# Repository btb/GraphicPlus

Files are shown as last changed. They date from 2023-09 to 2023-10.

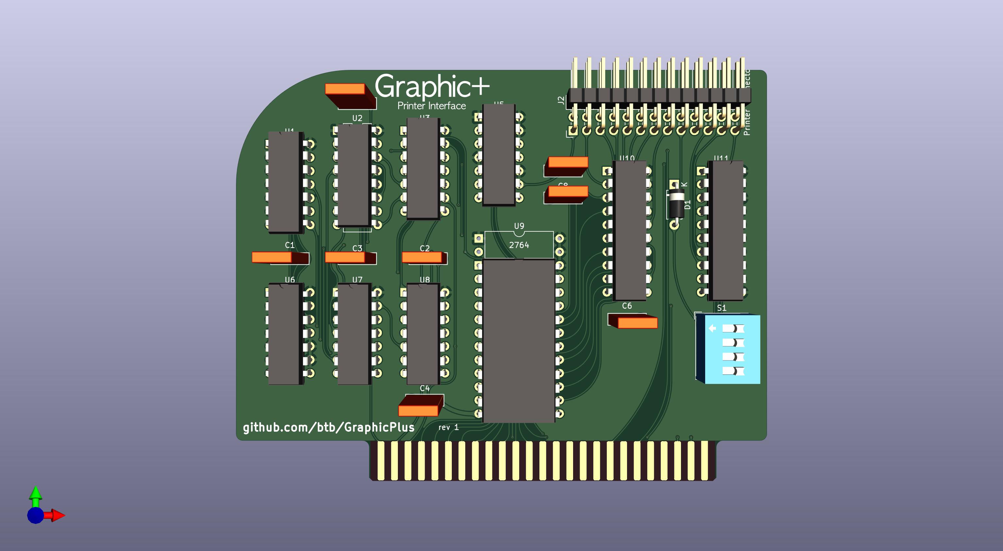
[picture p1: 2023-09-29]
GraphicPlus.jpg

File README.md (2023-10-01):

# GraphicPlus

Parallel printer card for Apple II

A clone of Orange Micro's Grappler+ printer card, from their published schematic, with the known bugfixes of their later revisions applied.

Component values not specified on the original schematic:

* C2, C4, C5, C5 - bypass capactors, 100nF should be fine.
* C1, C3, C7, C8 - on photos I've seen, C1 is 100pF, C3 is 470pF, C7 is 100pF. 100p for C8 should be fine as well.
* D1 - signal diode, 1n4148, 1n914, etc should be fine.

If you only want to use this as a firmware expansion card (i.e. for SoftSP), you can omit U5, U6, U10, U11, S1, D1, and J2.

Pins 2,4,6,8 of the port header are left unconnected for maximum compatibility with common PC parallel port IDC26F to DB25F dongles. If you need those pins to be connected to ground as in the original Grappler cards, short jumpers JP1,JP2,JP3,JP4.

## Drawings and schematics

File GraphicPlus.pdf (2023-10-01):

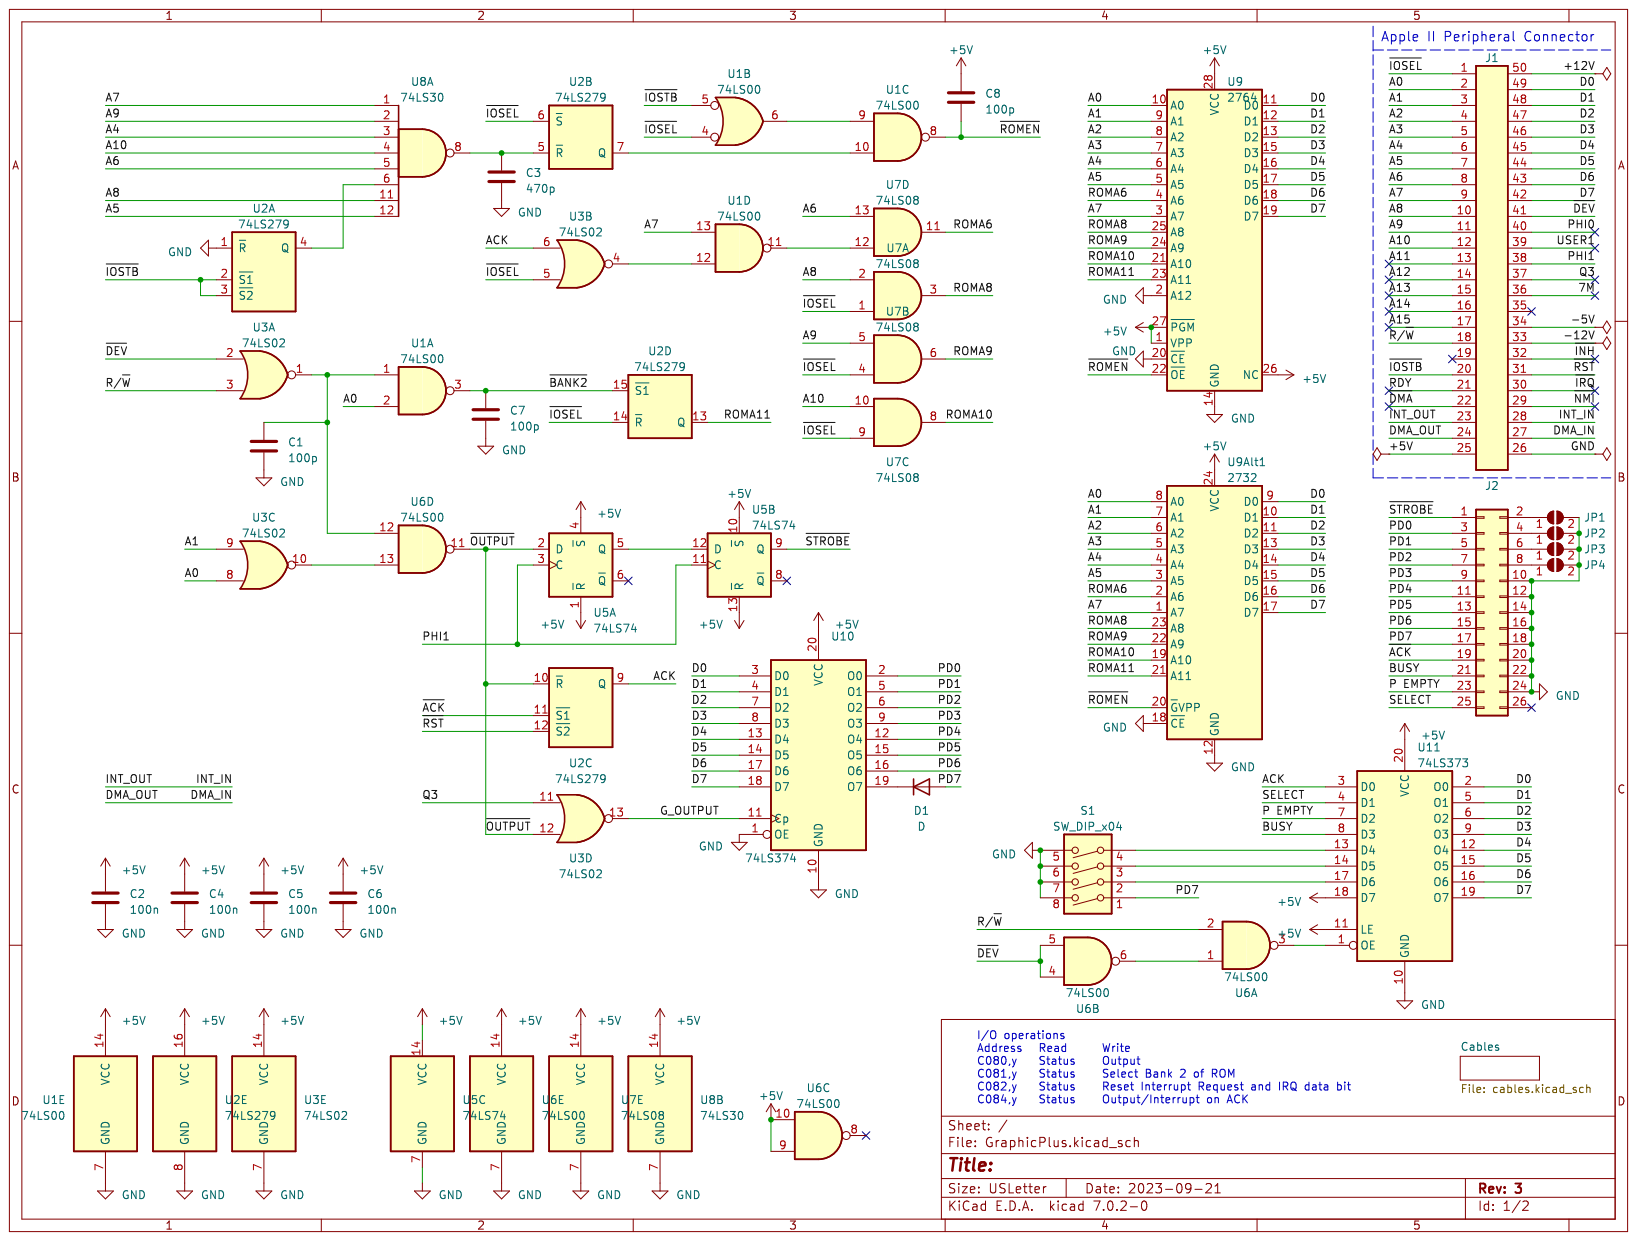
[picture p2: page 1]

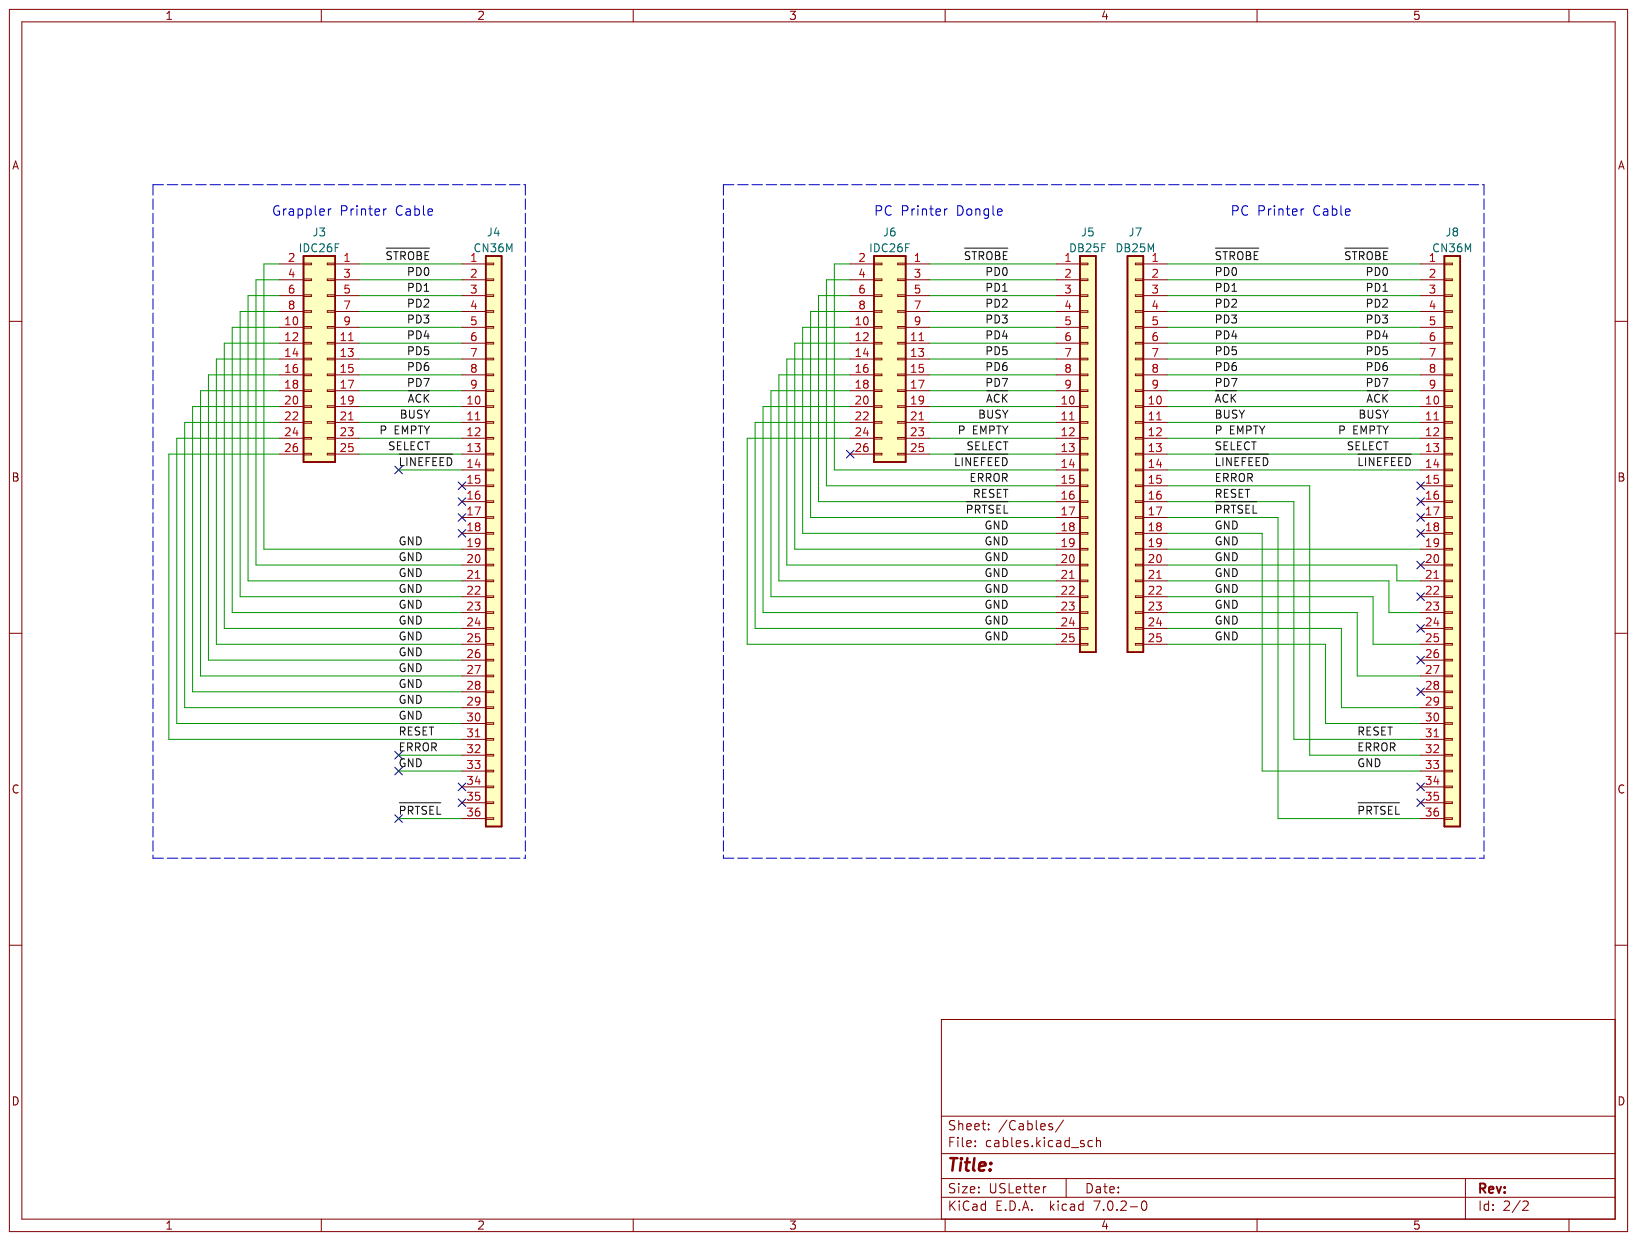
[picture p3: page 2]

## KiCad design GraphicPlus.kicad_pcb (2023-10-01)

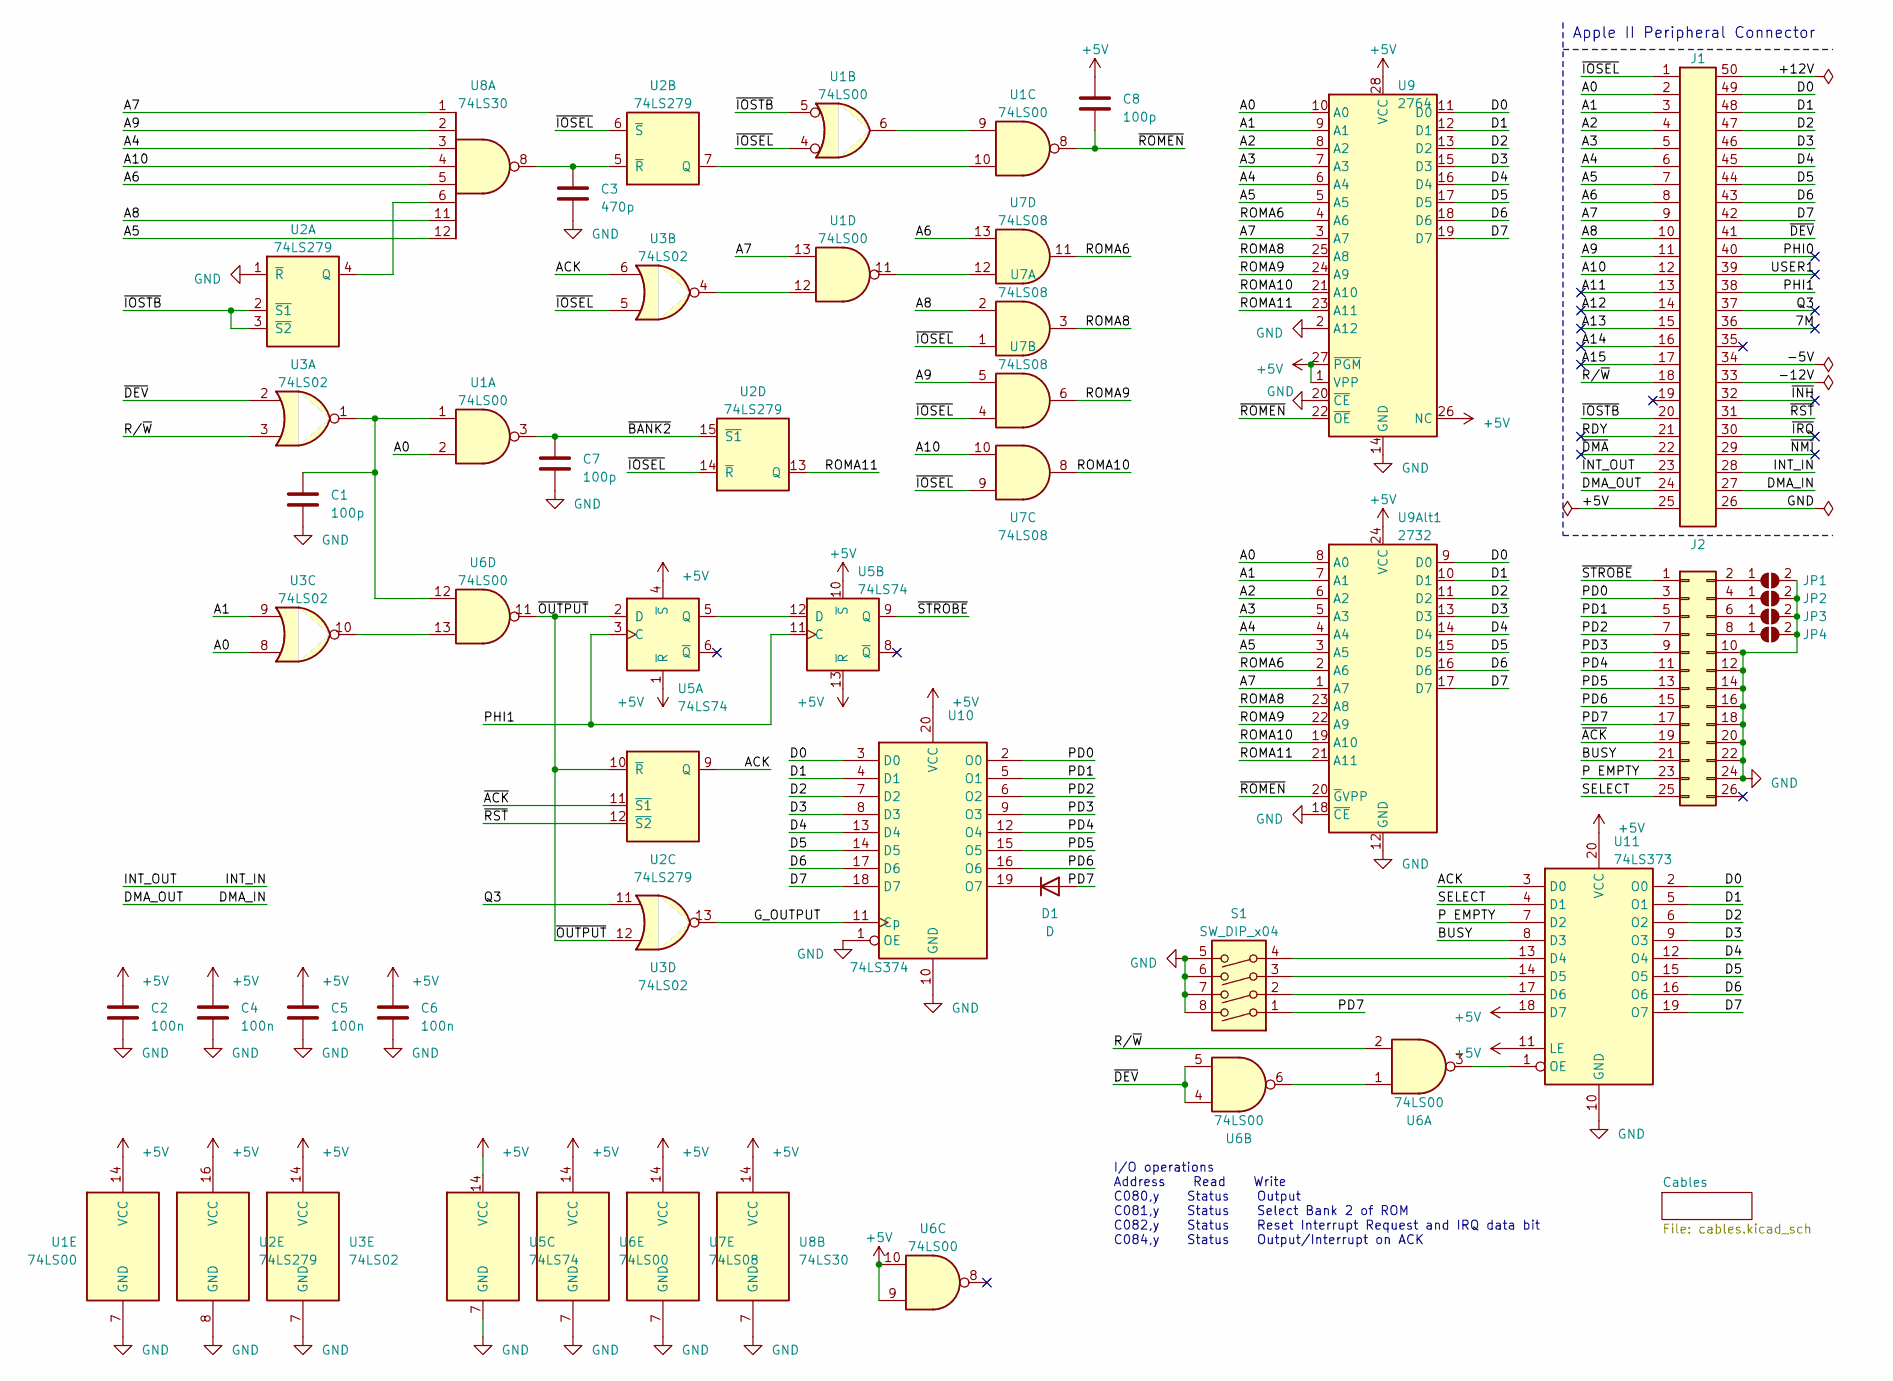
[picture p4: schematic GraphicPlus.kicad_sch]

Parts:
C1, C7, C8: 100p; C_Rect_L7.0mm_W2.0mm_P5.00mm
C2, C4, C5, C6: 100n; C_Rect_L7.0mm_W2.0mm_P5.00mm
C3: 470p; C_Rect_L7.0mm_W2.0mm_P5.00mm
D1: D; D_A-405_P7.62mm_Horizontal
J1: Apple II Expansion Bus; Apple II Expansion Edge Connector
J2: Printer Connector; PinHeader_2x13_P2.54mm_Horizontal
JP1, JP2, JP3, JP4: SolderJumper-2_P1.3mm_Open_RoundedPad1.0x1.5mm
S1: SW_DIP_x04; SW_DIP_SPSTx04_Slide_9.78x12.34mm_W7.62mm_P2.54mm
U1, U6: 74LS00; DIP-14_W7.62mm
U2: 74LS279; DIP-16_W7.62mm
U3: 74LS02; DIP-14_W7.62mm
U5: 74LS74; DIP-14_W7.62mm
U7: 74LS08; DIP-14_W7.62mm
U8: 74LS30; DIP-14_W7.62mm
U9: 2764; DIP-28_W15.24mm
U9Alt1: 2732; DIP-24_W15.24mm
U10: 74LS374; DIP-20_W7.62mm
U11: 74LS373; DIP-20_W7.62mm

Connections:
+5V: C2.1, C4.1, C5.1, C6.1, C8.1, J1.25 (+5V), U1.14 (VCC), U2.16 (VCC), U3.14 (VCC), U5.1 (~R), U5.4 (~S), U5.10 (~S), U5.13 (~R), U5.14 (VCC), U6.9, U6.10, U6.14 (VCC), U7.14 (VCC), U8.14 (VCC), U9.1 (VPP), U9.26 (NC), U9.27 (~PGM), U9.28 (VCC), U9Alt1.24 (VCC), U10.20 (VCC), U11.11 (LE), U11.18 (D7), U11.20 (VCC)
/7M: J1.36 (7M)
/+12V: J1.50 (-12V)
/-5V: J1.34 (-5V)
/-12V: J1.33 (-12V)
/A0: J1.2 (A00), U1.2, U3.8, U9.10 (A0), U9Alt1.8 (A0)
/A1: J1.3 (A01), U3.9, U9.9 (A1), U9Alt1.7 (A1)
/A2: J1.4 (A02), U9.8 (A2), U9Alt1.6 (A2)
/A3: J1.5 (A03), U9.7 (A3), U9Alt1.5 (A3)
/A4: J1.6 (A04), U8.3, U9.6 (A4), U9Alt1.4 (A4)
/A5: J1.7 (A05), U8.12, U9.5 (A5), U9Alt1.3 (A5)
/A6: J1.8 (A06), U7.13, U8.5
/A7: J1.9 (A07), U1.13, U8.1, U9.3 (A7), U9Alt1.1 (A7)
/A8: J1.10 (A08), U7.2, U8.11
/A9: J1.11 (A09), U7.5, U8.2
/A10: J1.12 (A10), U7.10, U8.4
/A11: J1.13 (A11)
/A12: J1.14 (A12)
/A13: J1.15 (A13)
/A14: J1.16 (A14)
/A15: J1.17 (A15)
/ACK: U2.9 (Q), U3.6, U11.3 (D0)
/BUSY: J2.21, U11.8 (D3)
/D0: J1.49 (D0), U9.11 (D0), U9Alt1.9 (D0), U10.3 (D0), U11.2 (O0)
/D1: J1.48 (D1), U9.12 (D1), U9Alt1.10 (D1), U10.4 (D1), U11.5 (O1)
/D2: J1.47 (D2), U9.13 (D2), U9Alt1.11 (D2), U10.7 (D2), U11.6 (O2)
/D3: J1.46 (D3), U9.15 (D3), U9Alt1.13 (D3), U10.8 (D3), U11.9 (O3)
/D4: J1.45 (D4), U9.16 (D4), U9Alt1.14 (D4), U10.13 (D4), U11.12 (O4)
/D5: J1.44 (D5), U9.17 (D5), U9Alt1.15 (D5), U10.14 (D5), U11.15 (O5)
/D6: J1.43 (D6), U9.18 (D6), U9Alt1.16 (D6), U10.17 (D6), U11.16 (O6)
/D7: J1.42 (D7), U9.19 (D7), U9Alt1.17 (D7), U10.18 (D7), U11.19 (O7)
/DMA_IN: J1.24 (DMA_OUT), J1.27 (DMA_IN)
/G_OUTPUT: U3.13, U10.11 (Cp)
/INT_IN: J1.23 (INT_OUT), J1.28 (INT_IN)
/P EMPTY: J2.23, U11.7 (D2)
/PD0: J2.3, U10.2 (O0)
/PD1: J2.5, U10.5 (O1)
/PD2: J2.7, U10.6 (O2)
/PD3: J2.9, U10.9 (O3)
/PD4: J2.11, U10.12 (O4)
/PD5: J2.13, U10.15 (O5)
/PD6: J2.15, U10.16 (O6)
/PD7: D1.2 (A), J2.17, S1.1
/PHI0: J1.40 (PHI0)
/PHI1: J1.38 (PHI1), U5.3 (C), U5.11 (C)
/Q3: J1.37 (Q3), U3.11
/RDY: J1.21 (RDY)
/ROMA6: U7.11, U9.4 (A6), U9Alt1.2 (A6)
/ROMA8: U7.3, U9.25 (A8), U9Alt1.23 (A8)
/ROMA9: U7.6, U9.24 (A9), U9Alt1.22 (A9)
/ROMA10: U7.8, U9.21 (A10), U9Alt1.19 (A10)
/ROMA11: U2.13 (Q), U9.23 (A11), U9Alt1.21 (A11)
/R/~W: J1.18 (R/~W), U3.3, U6.2
/SELECT: J2.25, U11.4 (D1)
/USER1: J1.39 (USER1)
/~ACK: J2.19, U2.11 (~S1)
/~BANK2: C7.1, U1.3, U2.15 (~S1)
/~DEV: J1.41 (~DEVICE_SELECT), U3.2, U6.4, U6.5
/~DMA: J1.22 (~DMA)
/~INH: J1.32 (~INH)
/~IOSEL: J1.1 (~IO_SELECT), U1.4, U2.6 (~S), U2.14 (~R), U3.5, U7.1, U7.4, U7.9
/~IOSTB: J1.20 (~I/O_STROBE), U1.5, U2.2 (~S1), U2.3 (~S2)
/~IRQ: J1.30 (~IRQ)
/~NMI: J1.29 (~NMI)
/~OUTPUT: U2.10 (~R), U3.12, U5.2 (D), U6.11
/~ROMEN: C8.2, U1.8, U9.22 (~OE), U9Alt1.20 (~GVPP)
/~RST: J1.31 (~RES), U2.12 (~S2)
/~STROBE: J2.1, U5.9 (Q)
GND: C1.2, C2.2, C3.2, C4.2, C5.2, C6.2, C7.2, J1.26 (GND), J2.10, J2.12, J2.14, J2.16, J2.18, J2.20, J2.22, J2.24, JP1.2 (B), JP2.2 (B), JP3.2 (B), JP4.2 (B), S1.5, S1.6, S1.7, S1.8, U1.7 (GND), U2.1 (~R), U2.8 (GND), U3.7 (GND), U5.7 (GND), U6.7 (GND), U7.7 (GND), U8.7 (GND), U9.2 (A12), U9.14 (GND), U9.20 (~CE), U9Alt1.12 (GND), U9Alt1.18 (~CE), U10.1 (OE), U10.10 (GND), U11.10 (GND)
unnamed: C1.1, U1.1, U3.1, U6.12
unnamed: D1.1 (K), U10.19 (O7)
unnamed: J2.2, JP1.1 (A)
unnamed: J2.4, JP2.1 (A)
unnamed: J2.6, JP3.1 (A)
unnamed: J2.8, JP4.1 (A)
unnamed: U1.6, U1.9
unnamed: U1.11, U7.12
unnamed: U1.12, U3.4
unnamed: U2.4 (Q), U8.6
unnamed: U1.10, U2.7 (Q)
unnamed: C3.1, U2.5 (~R), U8.8
unnamed: U3.10, U6.13
unnamed: U5.5 (Q), U5.12 (D)
unnamed: U6.1, U6.6
unnamed: S1.4, U11.13 (D4)
unnamed: S1.3, U11.14 (D5)
unnamed: S1.2, U11.17 (D6)
unnamed: U6.3, U11.1 (OE)

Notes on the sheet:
Apple II Peripheral Connector
I/O operations Address Read Write C080,y Status Output C081,y Status Select Bank 2 of ROM C082,y Status Reset Interrupt Request and IRQ data bit C084,y Status Output/Interrupt on ACK

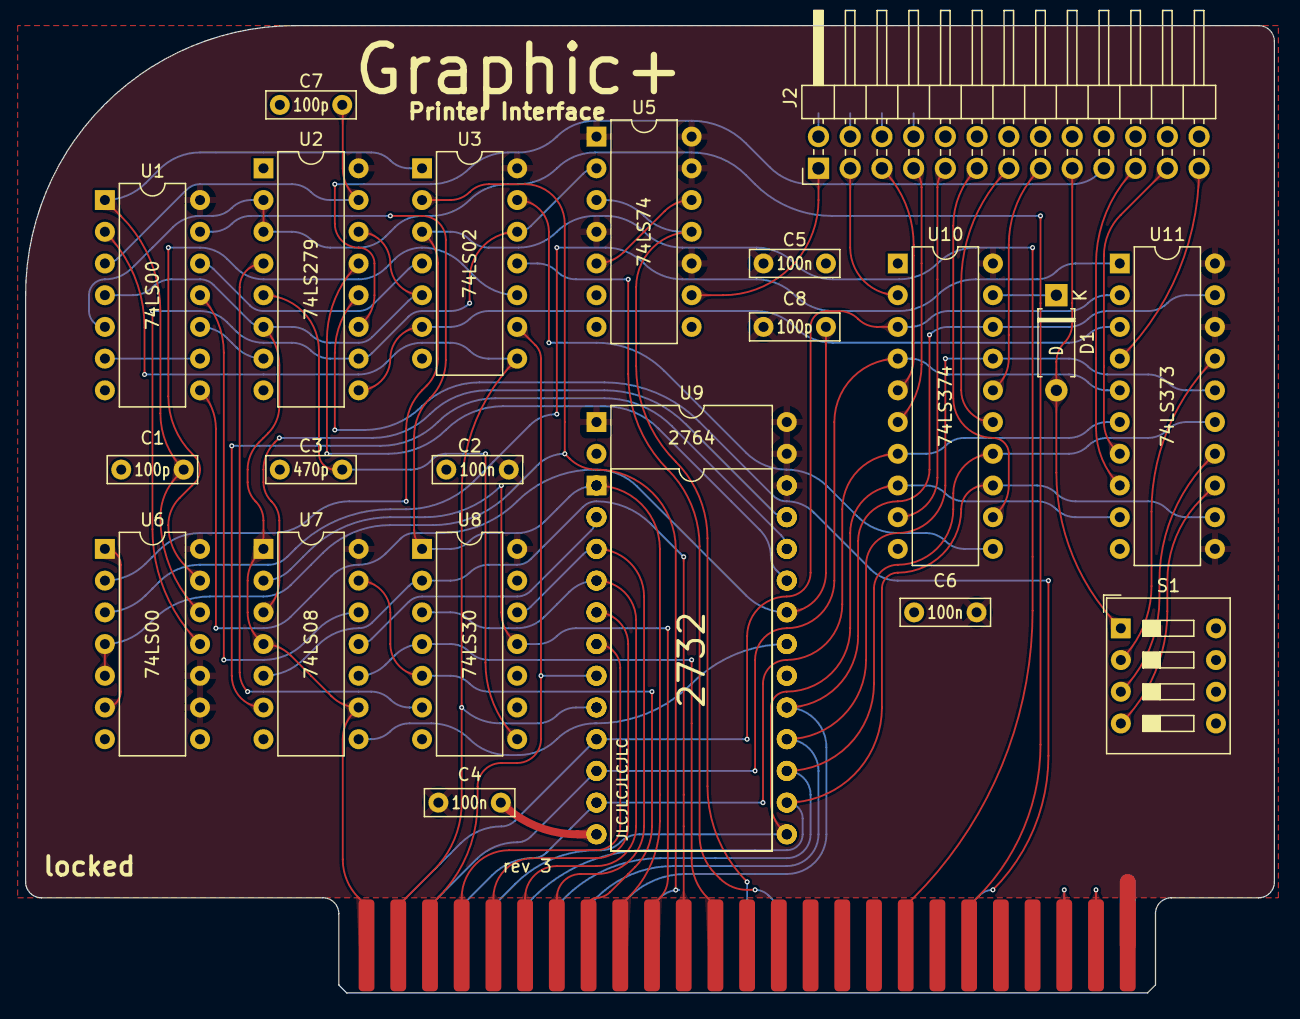
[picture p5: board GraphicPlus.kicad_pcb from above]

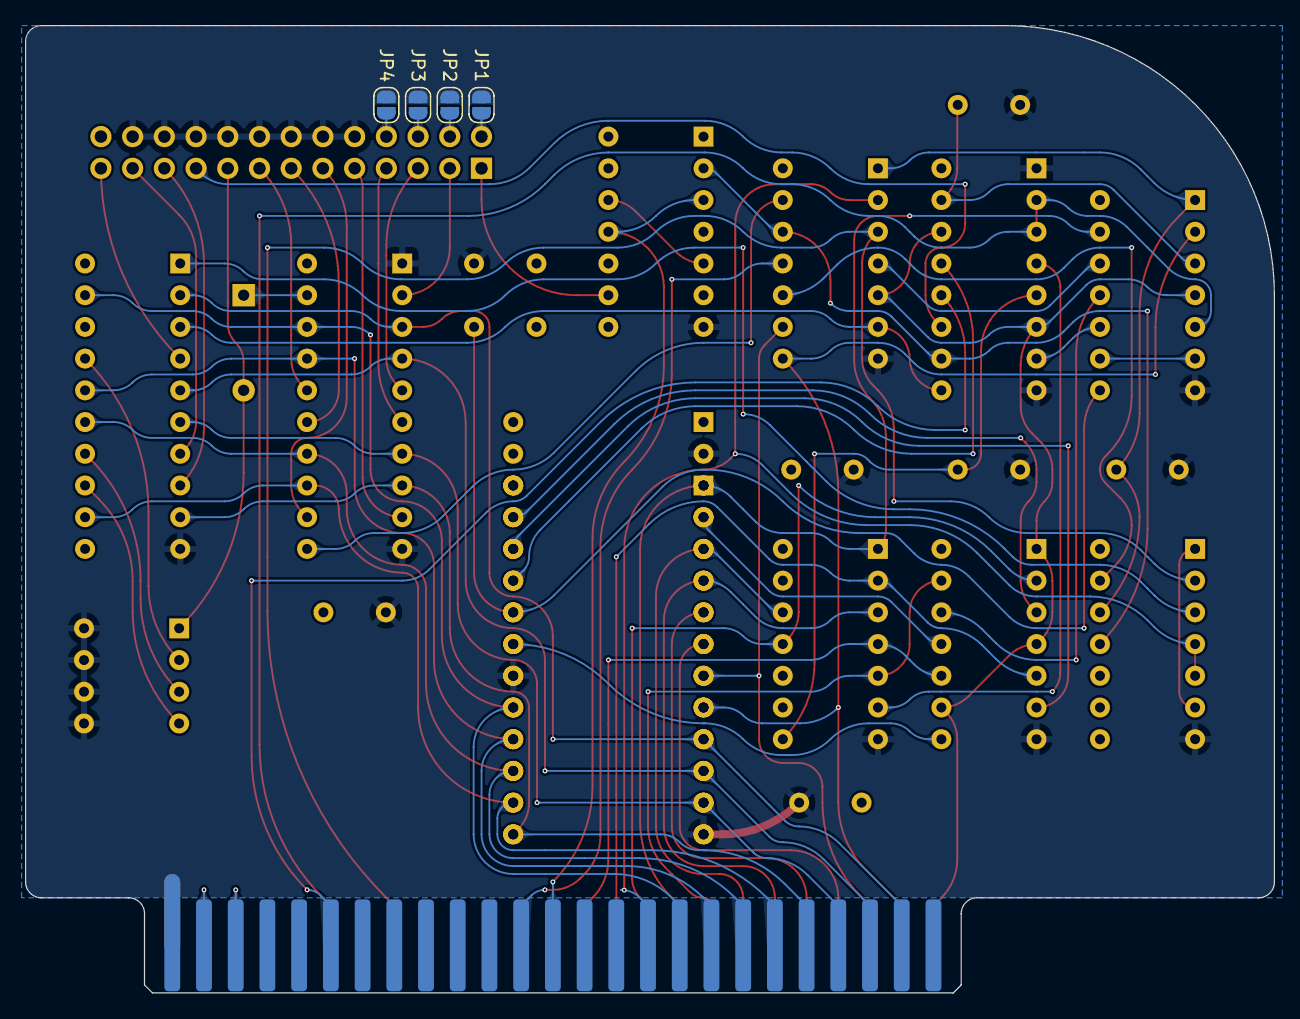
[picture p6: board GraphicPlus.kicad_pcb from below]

Board: 2 copper layers, 100.0 x 77.5 mm, 27 parts (4 on the bottom side), 72 nets.

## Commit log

2023-09-29 add kicad project
    [GraphicPlus.kicad_pcb, GraphicPlus.kicad_sch]
2023-09-29 native 374 version
    [GraphicPlus.kicad_pcb, GraphicPlus.kicad_sch]
2023-09-29 consolidate 74ls00 chips, better spacing
    [GraphicPlus.kicad_pcb, GraphicPlus.kicad_sch]
2023-09-29 rev 2, PC dongle compatibility
    [GraphicPlus.kicad_pcb, GraphicPlus.kicad_sch]
2023-09-29 finish up rev 1
    [GraphicPlus.kicad_pcb, GraphicPlus.kicad_sch]
2023-10-01 fix order number size
    [GraphicPlus.kicad_pcb]
2023-10-01 let power on pin 26 of DIP28 EPROM
2023-10-01 U2 pin 1 supposed to be GND, not +5
    [GraphicPlus.kicad_pcb, GraphicPlus.kicad_sch]
2023-10-01 Delete gerbers.zip
    rev2 defective
2023-10-01 force +5 on U9alt pin 26
    [GraphicPlus.kicad_pcb]
2023-10-01 rev3 fixes
    [GraphicPlus.kicad_pcb, GraphicPlus.kicad_sch]
